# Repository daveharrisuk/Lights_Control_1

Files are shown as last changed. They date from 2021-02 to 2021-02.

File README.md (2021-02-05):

# Lights_Control_1
Arduino Lighting control module for 10 LED strings.

10 PWM channels drive 10 LED strings. 

Input (Day/Night) triggers channel modes...

 DAYNIGHT : Duty cycle (DC) transition on trigger
 DAWN : DC transitions on input changing to day
 DUSK : DC transitions on input changing to night
 DUSKDAWN : DC transitions on input change
 NIGHTONOFF : During night time, LEDs transition at durations

Transition config:
 - Delay seconds before transitions.
 - Transition duration in seconds.

Duty Cycle Day and Night config.

Configurations are defined in seperate CONFIG.h file.
This sketch has 4 configs builtin. Address jumpers select 1 of 4 configs.

Over current protection. Audio alarm sounder.
Serial Monitor provides simple diagnostics. 

This version uses logic signal input (opto isolated) as day/night trigger.

Possible future options...
  SPI bus on PCB to have input trigger via CBUS.
  LCD via I2C bus & rotary encoder for local configuration method.

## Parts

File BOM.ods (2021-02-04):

Farnell | Order 79213245 25-Jan-2021. Bulk buy, enough for 10 modules plus spares. |  |  |  |  |  | Per Module
Code | Description | Manufacturer | Manufacturer Part | Qty | Price | Total | Qty | cost
3122019 | Voltage Series Regulator, Adjustable, SMD SOT-223 | TEXAS | LM1117IMP-ADJ | 12 | 0.7833 | 9.40 | 1 | 0.78
3212602 | Piezo Buzzer, 3V, 4KHZ; 75dBA; TH | TDK | PS1740P02E | 10 | 0.516 | 5.16 | 1 | 0.52
2211848 | Opto coupler, DC, SMD SO6 (4 pin) | TOSHIBA | TLP185 | 15 | 0.256 | 3.84 | 1 | 0.26
3405172 | MOSFET, N-CH, 20V, 3.5A, 0.5W; SMD SOT-323 | DIODES INC | DMN2058UW-7 | 120 | 0.0861 | 10.33 | 11 | 0.95
1740673 | Ceramic cap 100 nF, 50V X7R, SMD 0805 | AVX | 08055C104JAT2A | 30 | 0.095 | 2.85 | 1 | 0.10
3013472 | Ceramic cap 10 nF, 50 V X7R, SMD 0805 | SAMSUNG | CL21B103KCANNNC | 40 | 0.0255 | 1.02 | 3 | 0.08
1754086 | Tantalum cap 10µF, 16V, SMD 1206 | VISHAY | TR3A106K016C1700 | 20 | 0.446 | 8.92 | 2 | 0.89
1861170 | Resettable Fuse, SMD 1812, 12 VDC 1.5 A hold, 3 A trip | MULTICOMP | MC36231 | 15 | 0.116 | 1.74 | 1 | 0.12
2828288 | Resistor, 0R050, 2 W, SMD 2512 | MULTICOMP | MCLRP12FTWSR050 | 20 | 0.227 | 4.54 | 1 | 0.23
2447666 | Resistor, 47R, 125 mW, SMD 0805 | MULTICOMP | MCWR08X47R0FTL | 110 | 0.0061 | 0.67 | 11 | 0.07
2447618 | Resistor, 270R, 125 mW, SMD 0805 | MULTICOMP | MCWR08X2700FTL | 50 | 0.0072 | 0.36 | 1 | 0.01
2447662 | Resistor, 470R, 125 mW, SMD 0805 | MULTICOMP | MCWR08X4700FTL | 50 | 0.0064 | 0.32 | 1 | 0.01
2447587 | Resistor, 1k0, 125 mW, SMD 0805 | MULTICOMP | MCWR08X1001FTL | 50 | 0.0072 | 0.36 | 1 | 0.01
2447627 | Resistor, 2k7, 125 mW, SMD 0805 | MULTICOMP | MCWR08X2701FTL | 50 | 0.007 | 0.35 | 3 | 0.02
2447672 | Resistor, 4k7, 125 mW, SMD 0805 | MULTICOMP | MCWR08X4701FTL | 50 | 0.0072 | 0.36 | 1 | 0.01
2447553 | Resistor, 10k, 125 mW, SMD 0805 | MULTICOMP | MCWR08X1002FTL | 100 | 0.006 | 0.60 | 7 | 0.04
3234222 | Standard Recovery Diode, SMD DO-214 (SMA), 1 A | MULTICOMP | 1N4007 | 10 | 0.184 | 1.84 | 1 | 0.18
1675764 | Pin Header, 2.54 mm 2 way , MC34, TH Straight | MULTICOMP | MC34629 | 50 | 0.0154 | 0.77 | 1 | 0.02
1675754 | Connector Housing, 2.54 mm 2 Way (MC34 2218T contact) | MULTICOMP | MC34481 | 50 | 0.0176 | 0.88 | 1 | 0.02
3226076 | Shunt socket, for 2.54 mm header, 2 way | HARWIN | M7581-46 | 100 | 0.0456 | 4.56 | 2 | 0.09
2493646 | Terminal screw block, pluggable, 3.5mm; 2 way | CAMDENBOSS | CTB922HD/2 | 10 | 0.449 | 4.49 | 1 | 0.45
1841308 | Terminal block header, 3.5mm, 2 way, TH | WURTH | 691321100002 | 10 | 0.225 | 2.25 | 1 | 0.23
2847167 | Pin Header, 2.54 mm, 1 row, 22 way, TH | MULTICOMP | 2211S-22G | 40 | 0.114 | 4.56 | 2 | 0.23
1581242 | LED, SMD 0805 Green | MULTICOMP | MCL-S270GC | 10 | 0.085 | 0.85 | 1 | 0.09
1581241 | LED, SMD 0805 Yellow | MULTICOMP | MCL-S270YC | 10 | 0.091 | 0.91 | 1 | 0.09
1581239 | LED, SMD 0805 Red | MULTICOMP | MCL-S270SRC | 10 | 0.088 | 0.88 | 1 | 0.09
2217980 | LED, SMD 0805 Blue | KINGBRIGHT | KPT-2012QBC-D | 10 | 0.218 | 2.18 | 1 | 0.22
 |  |  |  | order total |  | 74.99 | sub t | 5.76
Other items |  |  |  | VAT | 15.0% | 11.25 | VAT | 0.86
 |  |  |  |  |  | 86.24 | sub t | 6.62
 | Mega 250 PRO (EMBED) {can be had cheaper from China} | eBay UK supplier ‘FamStore’ st-8078 |  | 6 | 9.83 | 58.98 | 1 | 9.83
 | Lights_Control PCB | JLCPCB |  | 10 | 1.604 | 16.04 | 1 | 1.60
 |  |  |  |  |  |  | total | 18.06

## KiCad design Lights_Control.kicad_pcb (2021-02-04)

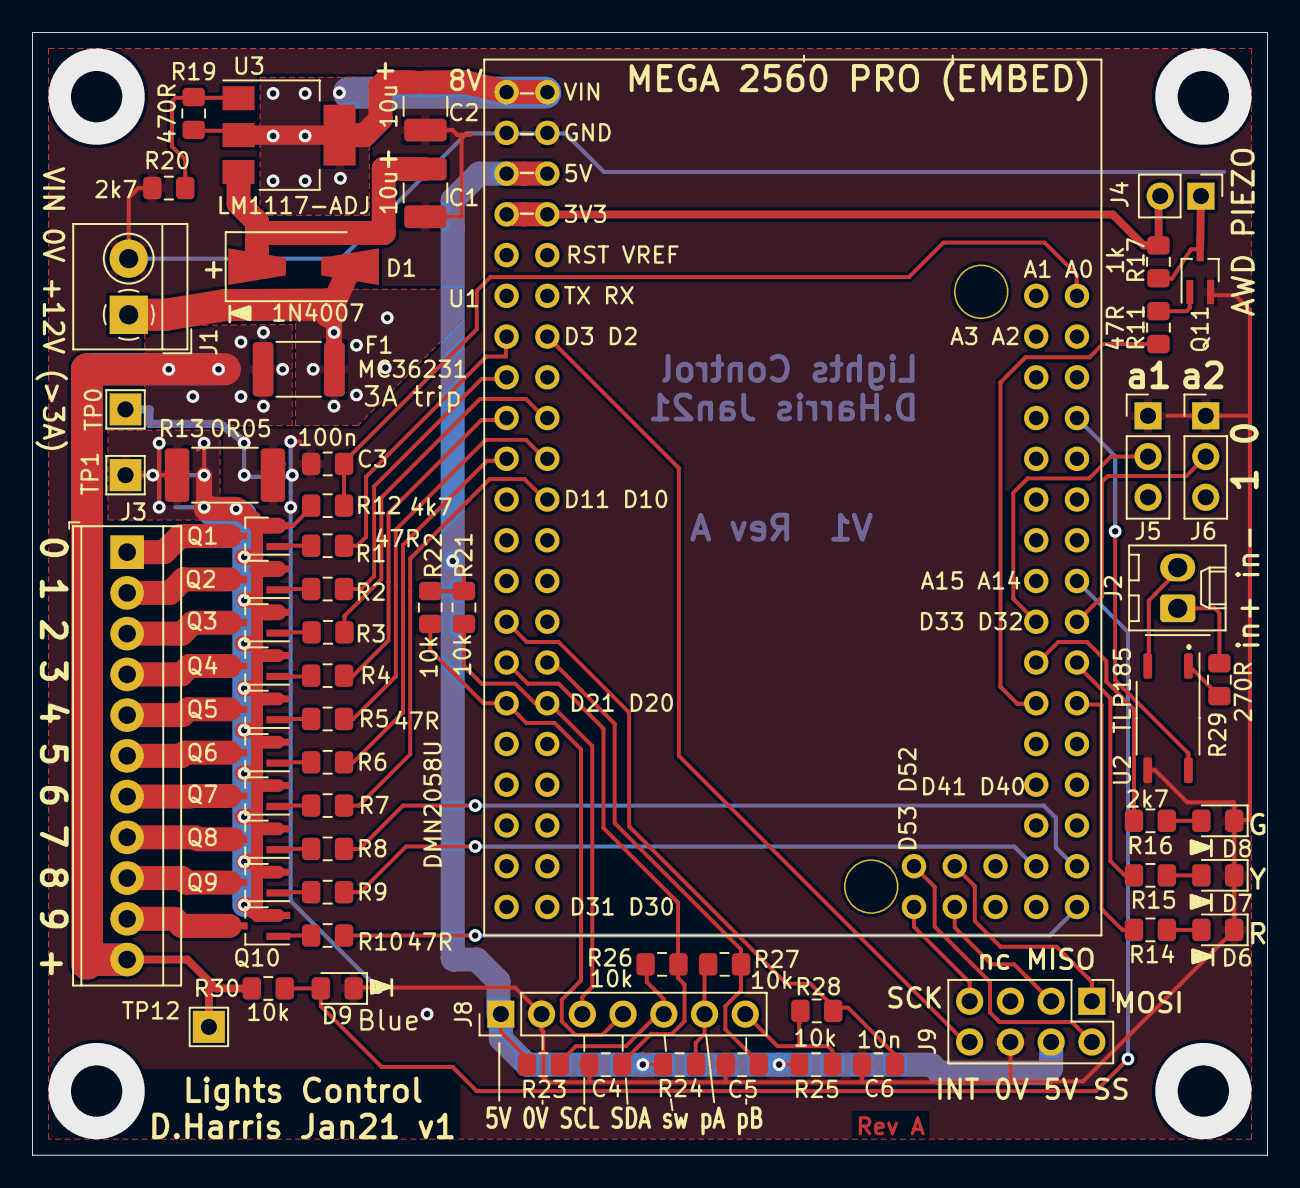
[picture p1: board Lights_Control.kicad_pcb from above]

Board: 2 copper layers, 77.0 x 70.0 mm, 66 parts (0 on the bottom side), 69 nets.

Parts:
C1, C2: 10u; C_1210_3225Metric_Pad1.42x2.65mm_HandSolder
C3: 100n; C_0805_2012Metric_Pad1.15x1.40mm_HandSolder
C4, C5, C6: 10n; C_0805_2012Metric_Pad1.15x1.40mm_HandSolder
D1: 1N4007; D_SMA-SMB_Universal_Handsoldering
D6: Red; LED_0805_2012Metric_Pad1.15x1.40mm_HandSolder
D7: Yellow; LED_0805_2012Metric_Pad1.15x1.40mm_HandSolder
D8: Green; LED_0805_2012Metric_Pad1.15x1.40mm_HandSolder
D9: Blue; LED_0805_2012Metric_Pad1.15x1.40mm_HandSolder
F1: MC36231; Fuse_1812_4532Metric_Pad1.30x3.40mm_HandSolder
J1: TH 3.5mm 2way Screw; TerminalBlock_4Ucon_1x02_P3.50mm_Horizontal
J2: TH 2.54mm 2way Molex KK; Molex_KK-254_AE-6410-02A_1x02_P2.54mm_Vertical
J3: TH 2.54mm 11way header; TerminalBlock_TE_1-282834-1_1x11_P2.54mm_Horizontal
J4: TH 2.54mm 2way header; PinHeader_1x02_P2.54mm_Vertical
J5: Conn_01x03_Male; PinHeader_1x03_P2.54mm_Vertical
J6: TH 2.54mm 3way header; PinHeader_1x03_P2.54mm_Vertical
J8: TH 2.54 7way socket; PinHeader_1x07_P2.54mm_Vertical
J9: TH 2.54mm 2 row 8 contact header; PinHeader_2x04_P2.54mm_Vertical
Q1, Q2, Q3, Q4, Q5, Q6, Q7, Q8, Q9, Q10, Q11: DMN2058U; SOT-323_SC-70_Handsoldering
R1, R2, R3, R4, R5, R6, R7, R8, R9, R10, R11: 47R; R_0805_2012Metric_Pad1.15x1.40mm_HandSolder
R12: 4k7; R_0805_2012Metric_Pad1.15x1.40mm_HandSolder
R13: 0R05; R_2512_6332Metric_Pad1.52x3.35mm_HandSolder
R14, R15, R16, R20: 2k7; R_0805_2012Metric_Pad1.15x1.40mm_HandSolder
R17: 1k; R_0805_2012Metric_Pad1.15x1.40mm_HandSolder
R19: 470R; R_0805_2012Metric_Pad1.15x1.40mm_HandSolder
R21, R22, R23, R24, R25, R26, R27, R28, R30: 10k; R_0805_2012Metric_Pad1.15x1.40mm_HandSolder
R29: 270R; R_0805_2012Metric_Pad1.15x1.40mm_HandSolder
TP0, TP1, TP12: TestPoint; TestPoint_THTPad_2.0x2.0mm_Drill1.0mm
U1: MEGA_PRO_EMBED_CH340G___ATMEGA2560; MEGA_2560_PRO(EMBED)
U2: TLP185; SOIC-4_4.55x3.7mm_P2.54mm
U3: LM1117-ADJ; SOT-223-3_TabPin2

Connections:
+3V3: J4.2, R17.2, U1.7, U1.8
+5V: J8.1, J9.4, R21.2, R22.2, R23.2, R24.2, R25.2, U1.5, U1.6
+12V: F1.1, J3.11, R30.1, TP12.1
/8V: C2.1, R19.2, U1.1, U1.2, U3.2
/12V: D1.2, F1.2, J1.1
/AWD: J4.1, Q11.3, R17.1
/AWDsig: R11.1, U1.59
/Adr1: J5.2, U1.63
/Adr2: J6.2, U1.64
/In+: J2.1, R29.1
/In-: J2.2, U2.3
/Input: U1.74, U2.6
/LED0: J3.1, Q1.3
/LED1: J3.2, Q2.3
/LED2: J3.3, Q3.3
/LED3: J3.4, Q4.3
/LED4: J3.5, Q5.3
/LED5: J3.6, Q6.3
/LED6: J3.7, Q7.3
/LED7: J3.8, Q8.3
/LED8: J3.9, Q9.3
/LED9: J3.10, Q10.3
/LEDgrn: R16.1, U1.61
/LEDred: R14.1, U1.60
/LEDyel: R15.1, U1.62
/Opto: R29.2, U2.1
/PHA: C5.1, R27.2, U1.30
/PHB: C6.1, R28.2, U1.27
/PWM0: R1.1, U1.13
/PWM1: R2.1, U1.15
/PWM2: R3.1, U1.18
/PWM3: R4.1, U1.17
/PWM4: R5.1, U1.20
/PWM5: R6.1, U1.19
/PWM6: R7.1, U1.22
/PWM7: R8.1, U1.52
/PWM8: R9.1, U1.51
/PWM9: R10.1, U1.47
/Q1g: Q1.1, R1.2
/Q2g: Q2.1, R2.2
/Q3g: Q3.1, R3.2
/Q4g: Q4.1, R4.2
/Q5g: Q5.1, R5.2
/Q6g: Q6.1, R6.2
/Q7g: Q7.1, R7.2
/Q8g: Q8.1, R8.2
/Q9g: Q9.1, R9.2
/Q10g: Q10.1, R10.2
/Q11g: Q11.1, R11.2
/SCL: J8.3, R21.1, U1.32
/SDA: J8.4, R22.1, U1.31
/SPI_INT: J9.8, U1.14
/SPI_MISO: J9.3, U1.44
/SPI_MOSI: J9.1, U1.49
/SPI_SCK: J9.7, U1.43
/SPI_SS: J9.2, U1.48
/SW: C4.1, R26.2, U1.29
/Sense: C3.1, R12.1, U1.80
/blue: D9.2, R30.2, U1.66
/grn: D8.2, R16.2
/pha-: J8.6, R24.1, R27.1
/phb-: J8.7, R25.1, R28.1
/red: D6.2, R14.2
/senseR: Q1.2, Q2.2, Q3.2, Q4.2, Q5.2, Q6.2, Q7.2, Q8.2, Q9.2, Q10.2, R12.2, R13.1, TP1.1
/sw-: J8.5, R23.1, R26.1
/yel: D7.2, R15.2
GND: C1.2, C2.2, C3.2, C4.2, C5.2, C6.2, D6.1, D7.1, D8.1, D9.1, J1.2, J5.1, J6.1, J8.2, J9.6, Q11.2, R13.2, R20.1, TP0.1, U1.3, U1.4, U2.4
unnamed: C1.1, D1.1, U3.3
unnamed: R19.1, R20.2, U3.1

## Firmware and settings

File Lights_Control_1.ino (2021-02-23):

/*file: Lights_Control_1.ino
 *-------------------------------------------------------------------------
*/
const char sTITLE[] = "\nLights_Control_1 © Dave Harris 23-Feb-2021 v1.03";
/*
 *
 * Layout lighting control module for multiple LED strings.
 *
 * Author: Dave Harris. Andover, UK.  MERG #2740.
 * 
 * - 10x 12 Volt PWM channels driving LED strings. 
 *
 * - Input (Day/Night) triggers channel modes...
 *    DAYNIGHT :   Duty cycle (DC) transition on input change
 *    DAWN :       DC transitions on input changing to day
 *    DUSK :       DC transitions on input changing to night
 *    DUSKDAWN :   DC transitions on input change
 *    NIGHTONOFF : During night time, LEDs transition at durations
 *
 * - Transition config...
 *    Delay seconds before transitions.
 *    Duty cycle Transition duration in seconds.
 *
 * - Duty Cycle for Day and Night in config.
 *
 * - Over current protection. Audio alarm sounder.
 * - simple diagnostics provided on Serial Monitor. 
 * 
 * - logic signal input (opto isolated) as day/night trigger.
 * 
 * - Configurations are defined in seperate CONFIG.h file.
 *    This contains 4 configs and address jumpers select which is used.
 *    The configs are compiled and uploaded along with the sketch.
 *    Address jumpers are read at boot/reset time.
 * 
 * Possible future options... (: we will see! :)
 *  SPI bus on PCB to have input trigger via CBUS.
 *  LCD via I2C bus & rotary encoder for local configuration method.
 *  
 * 
 * TargetPCB : Lights_Control V1.1 revB (see KiCad files)
 * MCU Board : 'MEGA 2560 PRO (EMBED)' (this should be OK on 'Arduino MEGA')
 * Processor : ATmega2560
 * Framework : Arduino 1.8.13
 * FlashMem  : 8.6k of 254k (3%)
 * GlobalRAM : 1.2k of 8k   (13%)
 * 
 *
 *---------------------------- History ------------------------------------
 * 
 *  4-Jan-2021 Dave Harris (DH) Project started
 *  9-Jan-2021 DH, v0.01  breadboard first test
 * 23-Jan-2021 DH, v0.02  add channel Modes
 *  2-Feb-2021 DH, v0.03  add TimerOne lib and 1 ms ISR
 *  4-Feb-2021 DH, v1.00  release
 *  5-Feb-2021 DH, v1.01  correct over Amp code. Part change C3 0.1uF > 1.0uF
 * 11-Feb-2021 DH, v1.02  efficiency and tidy up changes
 * 23-Feb-2021 DH, v1.03  Bug fix, DC wrong after over Amp condition
 * 
 * 
 *
 *---------------------------- include files --------------------------------
*/
 

#include "DATADEF.h"      /* data structure definitions                     */

#include "CONFIG.h"       /* user editable configuration tables             */

#include "PIN.h"          /* module pin definitions                         */

#include "GAMMA8.h"       /* Gamma correction table                         */

#include <TimerOne.h>     /* timer1 library for 1 ms ISR foreground process */



/*
 *------------------------------ globals -----------------------------------
*/


uint8_t  adr;                 /* address of CONFIG used 0-3  Set by setup() */


Input_t  input = UNDEF;       /* input state 0 DAY or 1 NIGHT               */
  

volatile var_t var[CHANQTY];  /* channel variable array. Is modified by ISR */


uint16_t amps = 0;            /* ADC reading of PINSENSE     0-1023         */


extern const Config_t  CONFIG[CONFIGQTY][CHANQTY];       /*  See CONFIG.h   */


uint8_t stopISR = false;             /* disable 1 ms ISR process, if true   */


bool silenceAlarm = false;




/*
 *---------------------- Ammeter calibrate -------------------------------
 * 
 * Rsense = 0R050,   2.0 A = 0.100 V on PINSENSE, into ADC
 * ADC range 0-1023, Vref = 1.10 V.  ADC reads 0.001074 V per unit. 
 * Max reading is 0.10 / 0.001074 = 93
*/

const uint16_t MAXAMPADCREAD = 93;   /* 2.0 A  ADC threshold              */

const uint16_t AMPCALIBRATE = 22;    /* ADC multiplier to give true Amps  */



/*
 *--------------------------------- functions ----------------------------
*/


void soundAlarm();                  /* sound piezo buzzer for 0.25 second */

void printStartMsg();               /* ident & config data to Serial      */

void printChanConfig(uint8_t chan); /* print channel config               */

void printVar( uint8_t chan );      /* print channel vars                 */

void printAmps();                   /* print calibrated mA                */

uint8_t readConfigAdr();            /* read config address jumpers        */

bool isInputChanged();              /* get and debounce input             */

bool isUnderVolt();                 /* sense blue LED to see if 12V is ok */

bool isOverAmp();                   /* read Volts on sense resistor       */

void overrideDC(uint8_t setval);    /* set new DC on channels             */

void restoreDC();                   /* reset DCs on channels              */

void testPower();                   /* test over Amp & under Volts        */

void startNewPhase();               /* setup next phase for chans         */

void processChannels();             /* foreground process, every 1 ms ISR */

void setupChannels();               /* initial set up of channels         */

void powerOnTest();                 /* show indicators and sound alarm    */

void setPinModes();                 /* configure pins                     */

void checkSerialSend();             /* get and action any Serial commands */

void setup();                       /* power on / reset initialisation    */

void loop();                        /* background process                 */



/*
 *--------------------------- soundAlarm() -------------------------------
 * 
 * Sound Audio Warning Device (piezo buzzer ~4 kHz) for 0.25 second.
*/

void soundAlarm()
{
  checkSerialSend();
  
  if( silenceAlarm == false )
  {
    for( uint16_t i = 0; i < 1000; i++ )
    {
      digitalWrite( PINAWDSIG, HIGH );
      delayMicroseconds( 121 );
      digitalWrite( PINAWDSIG, LOW );
      delayMicroseconds( 121 );
    } 
  }
  else
  {
    delay( 250 ); 
  }
}



/*
 *-------------------------- printStartMsg() -------------------------------
 * 
 * setup() calls this
*/

void printStartMsg()
{
  Serial.print( sTITLE );
  Serial.print(F(" Build "));
  Serial.println( __DATE__ );
  Serial.print(F("CONFIG.h="));
  Serial.println( sCONFIG_V );
  Serial.print(F("INPUTINVERT="));
  Serial.println( INPUTINVERT );
  Serial.print(F("CONFIG adr="));
  Serial.println( adr );
}



/*
 *---------------------------------- printChanConfig() ---------------------
 * 
 * print one channel config to Serial
*/

void printChanConfig( uint8_t chan )
{
  char str[70];
  static const char fmt[] = 
   "ch%u Tran:%03us Dly0:%03us Dly1:%03us dc0:%03u dc1:%03u step:%05ums %s";
  
  sprintf( str, fmt
     , chan                                       /* chan number          */
     , CONFIG[adr][chan].secTransit               /* Transit seconds      */
     , CONFIG[adr][chan].secDelay[0]              /* Delay 0 secs         */
     , CONFIG[adr][chan].secDelay[1]              /* Delay 1 secs         */
     , CONFIG[adr][chan].dc[0]                    /* duty cycle DC0       */
     , CONFIG[adr][chan].dc[1]                    /* duty cycle DC1       */
     , var[chan].msPerStep                        /* derived config value */
     , sMode[CONFIG[adr][chan].mode]              /* string, mode of chan */
    );
  Serial.println( str );
}



/*
 *-------------------------------- printVar() ------------------------------
 * 
 * print channel vars to Serial
*/

void printVar( uint8_t chan )
{
  char str[60];
  static const char fmt[] = " ch%u dc:%03u phase:%u state:%s";

  sprintf( str, fmt,
    chan, var[chan].dc, var[chan].phase, sState[var[chan].state] );
  Serial.println( str );
}



/*
 *------------------------------------------ printAmps() -------------------
 * 
 * prints, approx, measured mA to Serial
 * displays as multiples of 22 mA   ## anything below that shows as zero ##
*/

void printAmps()
{
  char str[60];
  static const char fmt[] = " %umA";
  sprintf( str, fmt, ( amps * AMPCALIBRATE ) );  /* test against DVM Amps */
  
  Serial.println( str );
}



/*
 *----------------------------------- readConfigAdr() ---------------------
 * 
 * read the config address from the address jumpers
*/

uint8_t readConfigAdr()
{                       /*  2^0 + 2^1 x2  */
  return digitalRead( PINADR0 ) + ( digitalRead( PINADR1 ) << 1 );
}



/*
 *----------------------------- isInputChanged() --------------------------
 * 
 * read output of opto, debounce and set global var input
 * 
 * return true if input changed and false if unchanged
*/

bool isInputChanged()
{
  static uint32_t msStamp  = 0;             /* timestamp last input change */

  bool rawInput = digitalRead( PININPUT );

  if( INPUTINVERT == true )
  {
    rawInput = ! rawInput;
  }
  
  if( ( rawInput != input ) && ( millis() > msStamp + 15 ) )
  {
    switch( input )
    {
      case UNDEF:
        input = (Input_t) rawInput;
        break;
      case DAY:
        input = NIGHT;
        break;
      case NIGHT:
        input = DAY;
        break;
    }

    msStamp = millis();

    digitalWrite( PINLEDGRN, input );

    Serial.println( sInput[input] );

    return true;
  }
  else
  {
    return false;
  }
}



/*
 *------------------------------ isUnderVolt() ---------------------------
 * 
 * If blue LED is not lit, the 12 V line failed or PolyFuse tripped
 * 12 V feeds onto Blue LED via 10k, Vf ~ 2.8 V. 
 * ADC ref is 1.1 V. If blue < 1.075 V (1000) then underVolt condition.
 * 
 * return true if under Volt and false if 12 V is OK
*/

bool isUnderVolt()
{
  return( analogRead( PINBLUE ) < 1000 ); 
}



/*
 *------------------------------ isOverAmp() ----------------------------
 * 
 * read Volts on sense resistor to measure Amps.
 * 
 * V1.01 code change, simplified.
 * Schematic change: C3 sense RC filter. Change 0.1 uF to 1.0 uF. PCB OK.
 * 
 * return true if over Amp and false if Amps OK
*/

bool isOverAmp()
{
  amps = analogRead( PINSENSE );
  
  return ( amps > MAXAMPADCREAD );
}



/*
 *----------------------------- overrideDC() ---------------------------
 * 
 * In case of over Amps, set channel duty cycle to lower value
 * 
 * Simplified in v1.01 and v1.03 code change.
*/

void overrideDC( uint8_t shiftR )
{
  
  for( uint8_t ch = 0; ch < CHANQTY; ch++ )
  {
    uint8_t newDC = var[ch].dc >> shiftR;     /* divide DC down       */
    
    analogWrite( PWMPIN[ch], GAMMA8[newDC] );
    
    Serial.print(" ");
    Serial.print( ch );
    Serial.print("=");
    Serial.print( newDC );
  }
  Serial.print(" >>");
  Serial.println( shiftR );
}



/*
 *------------------------------- restoreDC() ----------------------------
 * 
 * restore running dc
 * 
 * New in V1.01 code change. v1.03 add GAMMA lookup.
*/

void restoreDC()
{
  for( uint8_t ch = 0; ch < CHANQTY; ch++ )
  {
    analogWrite( PWMPIN[ch], GAMMA8[var[ch].dc] );
  }
}



/*
 *----------------------------------- testPower() --------------------------
 * 
 * If over current then reduce duty cycles and alarm.
 * If under Volt (poly fuse?) then just alarm.
 * Rewrite in V1.01 and v1.03 code change.
*/
void testPower()
{
  uint8_t shiftR = 1;                /* shiftR  1 is divide by 2          */
  
  while( isOverAmp() == true )       /* are we over Amps?                 */
  {
    stopISR = true;                  /* stop ISR as this code overides DC */
    
    digitalWrite( PINLEDRED, HIGH );
    Serial.print(F("OverAmp"));
    printAmps();

    if( shiftR < 8 )
    {
      overrideDC( shiftR++ );           /* cut DC by half                 */          
    }
    soundAlarm();                       /* constant beep beep beep beep   */
  }

  if( shiftR > 1 )
  {
    Serial.println(F("recover"));
    restoreDC();
  }
  
  stopISR = false;                 /* restart ISR processing LED channels */


  while( isUnderVolt() == true )
  {
    digitalWrite( PINLEDRED, HIGH );
    Serial.println(F("12Vtrip"));

    soundAlarm();                   /* beep pause beep pause beep...     */
    delay( 1000 );
  }

  digitalWrite( PINLEDRED, LOW );
}



/*
 *------------------------------ startNewPhase() --------------------------
 * 
 * The day/night input has changed, so setup new phase for each channel 
*/

void startNewPhase()
{
  stopISR = true;         /* all variables here are also manipulated by ISR */
  
  for( uint8_t ch = 0; ch < CHANQTY; ch++ )          /*  loop all channels  */
  {
    var[ch].secCount = 0;
    var[ch].msCount = 0;

    var[ch].state = TRANSIT;      /* default values - updated by switch     */
    var[ch].phase = 0;            /* this allows dc to transit back to dc0  */

    switch( CONFIG[adr][ch].mode )
    {
      case DAYNIGHT :             /* either input edge starts DAYNIGHT      */
        var[ch].state = DELAY;
        var[ch].phase = input;    /* phase 0 = 0 (day), phase 1 = 1 (night) */
        break;
        
      case DUSK :                 /* day to night starts dusk               */
        if( input == NIGHT )
        {
          var[ch].state = DELAY;
          var[ch].phase = 1;
        }
        break;
        
      case DAWN :                 /* night to day starts dawn               */
        if( input == DAY )
        {
          var[ch].state = DELAY;
          var[ch].phase = 1;
        }
        break;
        
      case DUSKDAWN :             /* either input edge starts dusk or dawn  */
        var[ch].state = DELAY;
        var[ch].phase = 1;
        break;
        
      case NIGHTONOFF :           /* day to night starts NightOnNOff        */
        if( input == NIGHT )
        {
          var[ch].state = DELAY;
          var[ch].phase = 1;
        }
        break;
    }
  }                              /* end of loop                             */
  stopISR = false;
}



/*
 *-------------------------- processChannels() -----------------------------
 * 
 * timer1 Interrupt Service Routine runs every 1 milli second
 * 
 * Cycle though the channels and process them
 * 
 * target DutyCycle, dc, is CONFIG[ch].dc[phase]      0-255
 * current dc is in var[ch].dc                        0-255
 * ms counter is in var[ch].msCount (step & Delay)    0-65k
 * Delay seconds counter is in var[ch].secCount       0-255
 * secs to delay is in CONFIG[ch].secDelay[phase]     0-255
 * ms between inc/dec steps is in var[ch].msPerStep   0-65k
*/

void processChannels()         /* ! This is an ISR which runs every 1 ms  ! */
{  
  SetPINTP_D31;                /* Scope TP on pin D31 ~= ISR run time       */
                               /* on ATmega2560 = min 21 us to peak 87 us   */

  bool transits = false;       /* lights LED_builtin if Transits are active */


  if( stopISR == false )                  /* allow this to change DC values */
  {
                                                   /* loop all channels     */
    for( uint8_t ch = 0; ch < CHANQTY; ch++ )
    {
  
      if( var[ch].state != STEADY )                /* is state not STEADY?  */
      {
        var[ch].msCount++;
        
        if( var[ch].state == DELAY )                 /* is state DELAY?     */
        {
  
          if( var[ch].msCount > 1000 )               /* count delay seconds */
          {
            var[ch].msCount = 0;
            var[ch].secCount++;
            
            if( var[ch].secCount > CONFIG[adr][ch].secDelay[var[ch].phase] )
            {
              var[ch].state = TRANSIT;               /* end state DELAY     */
              var[ch].secCount = 0;
            }
          }
        }
        else                                  /* we deduce state is TRANSIT */
        {
          transits = true;                           /* drives LED_builtin  */
          
          if( var[ch].msCount > var[ch].msPerStep )
          {
            var[ch].msCount = 0;
            if( var[ch].dc == CONFIG[adr][ch].dc[var[ch].phase] )
            { 
              var[ch].state = STEADY;                /* dc transit complete */
              
              switch( CONFIG[adr][ch].mode )         /* trigger a new phase */
              {
                case NIGHTONOFF :
                  if( input == NIGHT )
                  {
                    var[ch].phase = ! var[ch].phase;
                    var[ch].state = DELAY;
                  }
                  break;
  
                case DUSK :
                  if( var[ch].phase == 1 )
                  {
                    var[ch].phase = 0;
                    var[ch].state = DELAY;                  
                  }
                  break;
                  
                case DAWN :
                  if( var[ch].phase == 1  )
                  {
                    var[ch].phase = 0;
                    var[ch].state = DELAY;                  
                  }
                  break;
                  
                case DUSKDAWN :
                  if( var[ch].phase == 1 )
                  {
                    var[ch].phase = 0;
                    var[ch].state = DELAY;
                  }
                  break;
                  
                case DAYNIGHT : 
                  break;
              }
            }
            else            /* in Transit & current DC is GT or LT target DC */
            {
              if( var[ch].dc > CONFIG[adr][ch].dc[var[ch].phase] ) /* which? */
              {
                var[ch].dc--;                             /* GT so decrement */
              }
              else
              {
                var[ch].dc++;                             /* LT so increment */
              }
              analogWrite( PWMPIN[ch], GAMMA8[var[ch].dc] );   /* set new dc */
            }
          }
        }
      }  /* end if state not STEADY   */
    }  /* end for ch loop             */
  
    digitalWrite( LED_BUILTIN, transits );          /* show TRANSIT activity */
    
  } /* end not stopISR   */
  
  ClrPINTP_D31;   /* pin high, then low = ISR run time */
}



/*
 *---------------------- setupChannels() -----------------------------------
 * 
 * preset channel variables derived from channel constants and start the PWM
 *  
 * called from setup(), before timerOne is started
*/

void setupChannels()
{
  for( uint8_t ch = 0; ch < CHANQTY; ch++ )     /* loop through channels   */
  {
    if( CONFIG[adr][ch].secTransit == 0 )    /* zero sec transit is special */
    { 
      var[ch].msPerStep = 1;    /* dc transits rapidly to target duty cycle */
    }
    else                        /* non-zero transit secs, calc ms per step  */
    {
      uint16_t diff = abs( CONFIG[adr][ch].dc[0] - CONFIG[adr][ch].dc[1] );
      
      uint32_t msCalc = ( CONFIG[adr][ch].secTransit * 1000UL ) / diff;
      
      if( msCalc > MAXmsPERSTEP )    /* long Transit & tiny diff overflows  */
      {                              /* when abs(DC0 - DC1) is less than 4. */
        msCalc = MAXmsPERSTEP;       /* Limit step transit ms.              */
      }
      var[ch].msPerStep = (uint16_t) msCalc;
    }
    
    var[ch].dc = MAXDC / 2;             /* or... CONFIG[adr][ch].dc[input]; */

    analogWrite( PWMPIN[ch], var[ch].dc );        /* set DC of PWM channel  */
    
    printChanConfig( ch );
  } 
  delay( 500 );
  
  startNewPhase();
}



/*
 *------------------------------- powerOnTest() ----------------------------
 * 
 * setup() calls this
*/

void powerOnTest()
{
  for( uint8_t ch = 0; ch < CHANQTY; ch++ )
  {
    analogWrite( PWMPIN[ch], 5 );     /* start PWM channel at DC 5/255 = 2% */
  }
  
  pinMode( PINTP_D30, OUTPUT );       /* Test Point: TBA                    */
  SetPINTP_D30;                       /* macro fast pin method. See PIN.h   */
  ClrPINTP_D30;
  
  pinMode( PINTP_D31, OUTPUT );       /* Test Point: measure ISR duration   */
  SetPINTP_D31;
  ClrPINTP_D31;                       /* macro fast pin method. See PIN.h   */
  
  digitalWrite( PINLEDRED, 1 );       /* light LEDs & AWD sound test        */
  digitalWrite( PINLEDYEL, 1 );       /*                                    */
  digitalWrite( PINLEDGRN, 1 );       /*                                    */
  digitalWrite( LED_BUILTIN, 1 );     /* all LED flash ...                  */
  soundAlarm();                       /* test AWD, short beeep              */
  digitalWrite( PINLEDRED, 0 );       /* end power on tests, reset all LED  */
  digitalWrite( PINLEDYEL, 0);        /*                                    */ 
  digitalWrite( PINLEDGRN, 0 );       /*                                    */
  digitalWrite( LED_BUILTIN, 0 );     /*                                    */  
}



/*
 *--------------------------- setPinModes() --------------------------------
 * 
 * setup() calls this
*/

void setPinModes()
{
  pinMode( PININPUT,  INPUT_PULLUP ); /* Day or Night via opto isolate      */
  pinMode( PINADR0,   INPUT_PULLUP ); /* Config Address bit 2^0 jumper link */
  pinMode( PINADR1,   INPUT_PULLUP ); /* Config Address bit 2^1 jumper link */
  pinMode( PINTACTSW, INPUT_PULLUP ); /* Tactile push switch - TBA          */
  
  pinMode( PINBLUE,   INPUT );        /* 12 V sensed on blue LED into ADC   */
  pinMode( PINENCPHA, INPUT );        /* Rotary encoder phase A via lowpass */
  pinMode( PINENCPHB, INPUT );        /* Rotary encoder phase B via lowpass */
  pinMode( PINENCSW,  INPUT );        /* Rotary encoder switch via lowpass  */
  pinMode( PINSENSE,  INPUT );        /* input yes, but is ADC              */
  
  pinMode( PINAWDSIG, OUTPUT );       /* AudioWarningDevice: Piezo buzzer   */
  pinMode( PINLEDRED, OUTPUT );       /* Red LED: over Amp/under Volt alarm */
  pinMode( PINLEDYEL, OUTPUT );       /* Yellow LED:  TBA                   */
  pinMode( PINLEDGRN, OUTPUT );       /* Green LED: input state LED         */
  pinMode( LED_BUILTIN, OUTPUT );     /* Red LED on MEGA, DC Transit active */
}
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
void loop()
{   
  testPower();
  
  if( isInputChanged() == true )
  {
    startNewPhase();
  }

  checkSerialSend();

} /* restart loop() */


/*
 *--------- Lights_Control_1.ino -------------------- EoF ------------------
*/

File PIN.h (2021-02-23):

/*file: PIN.h     This is include file for Lights_Control_1.ino sketch
 *------------------------------------------------------------------------------
 *
 * Lighting Control module for 10 channels
 * 
 * Author: Dave Harris. Andover, UK.    © Dave Harris 2021
 * 
 * IO pin definitions
 * 
 * Target MCU is Arduino compatable 'MEGA 2560 PRO (EMBED)' or Arduino 'MEGA'
 * 
 * Target PCB is Lights_Control_1   V1 Rev A
 * 
*/
#ifndef PIN_h_  /* include guard */
#define PIN_h_


/* Define the pins used
 * ---------------------
 *  
 *  
 * MEGA ATmega2560 has...
 *  External interrupt INT pins are 2, 3, 18, 19, 20 and 21. 
 *   2/3 used by timer comparators 3B and 3C. 2 assigned to SPI_INT.
 *   18/19 free, assigned to Encoder. 
 *   20/21 reserved for I2C. 
 *
 *  The choice of pins for PWM is governed by the usage of timers(0-5) and
 *   timer comparators (A, B & C) and their pins.
 * 
 *  Following PWM pins and timer usage...
 *  Pin Timer Usage by fuction/library
 *  --- ----  -------------------------
 *   2  3B    Free, but is an INT pin. Assigned to SPI_INT signal.
 *   3  3C    Free.  Assigned to PWM0.
 *   4  0B    millis, used in this code.
 *   5  3A    Free.  Assigned to PWM1.
 *   6  4A    Free.  Assigned to PWM2.
 *   7  4B    Free.  Assigned to PWM3.
 *   8  4C    Free.  Assigned to PWM4.
 *   9  2B    tone, lib not used.  Assigned to PWM5.
 *  10  2A    tone, lib not used.  Assigned to PWM6.
 *  11  1A    timer1/servo. TimerOne lib used in this code.
 *  12  1B    timer1/servo. TimerOne lib used in this code.
 *  13  0A    millis, used in this code.
 *  44  5C    Free.  Assigned to PWM7.
 *  45  5B    Free.  Assigned to PWM8.
 *  46  5A    Free.  Assigned to PWM9.
 *  
*  
 * Array of PWM pins
*/
const uint8_t PWMPIN[CHANQTY] = { 3, 5, 6, 7, 8, 9, 10, 44, 45, 46};


/* Alarms and status                                                */

const uint8_t PINAWDSIG = 37; /* AudioWarningDevice signal          */

const uint8_t PINLEDRED = 36; /* Red LED.    Error                  */

const uint8_t PINLEDGRN = 35; /* Green LED.  Status green           */

const uint8_t PINLEDYEL = 34; /* Yellow LED. Status yellow          */


/* Module address input. Allows 4 configs in sketch, in CONFIG.h    */

const uint8_t PINADR0 = 33;   /* module config address 2^0 = 0 or 1 */
const uint8_t PINADR1 = 32;   /* module config address 2^1 = 0 or 2 */


/* inputs                                                           */

const uint8_t PINSENSE = A0;   /* All MOSFET via 0R05 for 3.0 A max */

const uint8_t PININPUT = A6;   /* module input via OptoIsolator     */

const uint8_t PINTACTSW = A12; /* Tactile push button switch        */

const uint8_t PINBLUE = A14;   /* PolyFuse sense, Volts on blue LED */


/* SPI bus   ### for future upgrade ###                             */

const uint8_t PINSPIMISO = 50; /* Master In, Slave Out  (HW SPI 50) */
const uint8_t PINSPIMOSI = 51; /* Master Out, Slave In  (HW SPI 51) */
const uint8_t PINSPISCK  = 52; /* clock                 (HW SPI 52) */
const uint8_t PINSPISS   = 53; /* Slave Select                      */
const uint8_t PINSPIINT  = 2;  /* Interrupt (must be an INT pin)    */


/* Rotary Encoder    ### for future upgrade ###                     */

const uint8_t PINENCPHA = 18;  /* encoder phase A (must be INT pin) */
const uint8_t PINENCPHB = 17;  /* encoder phase B                   */
const uint8_t PINENCSW  = 19;  /* encoder SW (must be INT pin)      */


/* I2C bus    ### for future upgrade ###                            */

const uint8_t PINI2CSCL = 20;  /* I2C clock     (HW I2C pin is 20 ) */
const uint8_t PINI2CSDA = 21;  /* I2C data      (HW I2C pin is 21 ) */


const uint8_t PINTP_D30 = 30;  /* MEGA MCU pin D30 maps CPU pin PC7 */
                               /* macros to fast digitalWrite       */
#define SetPINTP_D30   PORTC = PORTC | B10000000
#define ClrPINTP_D30   PORTC = PORTC & B01111111


const uint8_t PINTP_D31 = 31;  /* MEGA MCU pin D31 maps CPU pin PC6 */
                               /* macros to fast digitalWrite       */
#define SetPINTP_D31   PORTC = PORTC | B01000000
#define ClrPINTP_D31   PORTC = PORTC & B10111111


#endif /* PIN_h_  */
/* -------------------------------EoF------------------------------ */
